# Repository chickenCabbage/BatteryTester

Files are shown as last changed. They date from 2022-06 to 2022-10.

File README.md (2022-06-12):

# BatteryTester
ATmega-based battery tester for FIRST Robotics batteries, designed for ease-of-use for FIRST students and with built-in safety features.

The tester is soldered onto perfboard and is run by a "bare" ATmega328P. It tests battery voltage and state-of-charge using the internal ADC.
Battery internal resistance is tested using high-current loads switched with MOSFETs - by measuring the voltage at the battery terminals under different currents, the tester can calculate the resistance per Ohm's Law.

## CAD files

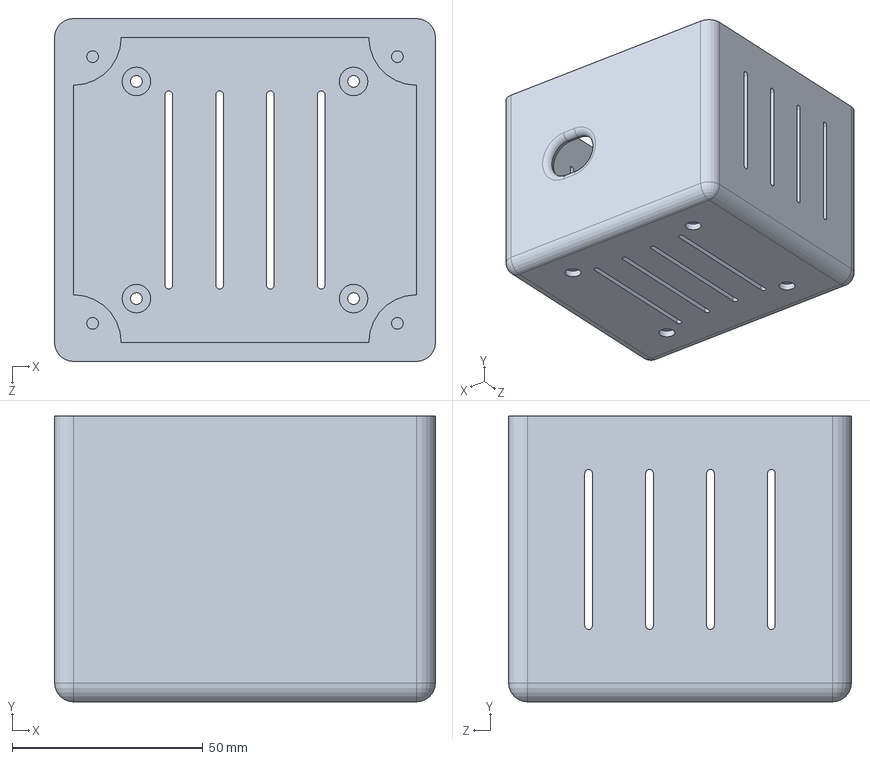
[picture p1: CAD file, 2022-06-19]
3D/Box.SLDPRT
100.0 x 75.0 x 90.0 mm

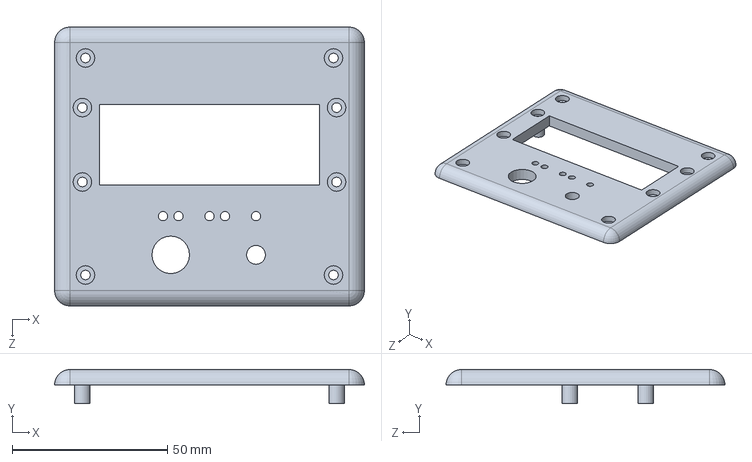
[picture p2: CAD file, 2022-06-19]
3D/Lid.SLDPRT
100.0 x 11.0 x 90.0 mm

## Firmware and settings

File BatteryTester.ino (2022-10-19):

//Pins translation from ATmega328P hardware to Arduino pins according to:
//https://upload.wikimedia.org/wikipedia/commons/c/c9/Pinout_of_ARDUINO_Board_and_ATMega328PU.svg

#define debug false			//print to serial
#define pbPin 1				//PD1, ATmega pin 3

#define quickRunPin 2		//PD2, ATmega pin 4
bool quickRun = false;		//skip the start PB and shorten display times?
#define QUICKFACTOR 2		//by how much are quickRun delays faster?

#define delayPotPin A3		//PC3, ATmega pin pin 26
int printDelay = 1000;		//display time

#define socOnlyPin 0	//PD0, ATmega pin 2
bool socOnly = false;	//show only SOC vs SOC+SOH

#include <LiquidCrystal.h>
#define rs 5	//PD5, ATmega pin 11
#define en 11	//PB3, ATmega pin 17
#define d4 10	//PB2, ATmega pin 16
#define d5 9	//PB1, ATmega pin 15
#define d6 12	//PB4, ATmega pin 18
#define d7 13	//PB5, ATmega pin 19
LiquidCrystal lcd(rs, en, d4, d5, d6, d7);
//16 chars, 2 lines:
#define LCDCOL 16
#define LCDROW 2

#define pbLEDPin 3		//PD3, ATmega pin 5
#define indicatorPin 4	//PD4, ATmega pin 4
#define backlightPin 8	//PE0, ATmega pin 14

#define hcPin A1 //PC2, ATmega pin 25
#define lcPin A2 //PC1, ATmega p  in 24
enum state {
	EC, //extreme current
	HC, //high current
	LC, //low current
	OFF //no current
};

#define BLINKINTERVAL 500	//how long is a blink half-cycle
#define PBCHECKDELAY  10	//how often to check for PB

byte nextChar[] = { //filled arrow right symbol
	B00000,
	B01000,
	B01100,
	B01110,
	B01111,
	B01110,    
	B01100,
	B01000
};

byte omegaChar[] = { //omega/ohms symbol
	B00000,
	B01110,
	B10001,
	B10001,
	B10001,
	B01010,
	B11011,
	B00000
};

#define voltsPin		A5	//PC5, ATmega pin 28
#define ampsPin			A4	//PC3, ATmega pin 27
#define MEASURMENTAMNT	512 //amount of measurments to take
#define MEASURMENTDELAY	2	//interval between each measurment

#define MAXVOLTS	15.4	//max voltage measurable [volts]
#define ISSADC		514		//steady state current [ADC]
#define ISSAMPS		0.035	//steady state current [amps]
#define MAXCURRENT	3.55	//max current measurable [amps]
/* calculation looks ~ like this:
 * avgVolts = map(avgVolts, 0, 1024, 0, MAXVOLTS);
 * avgAmps  = map(avgAmps,  ISSADC, 1024, ISSAMPS, MAXCURRENT);
 */
#define SOC100	13.5 //100% state of charge voltage
#define SOC0	10.5 //0% state of charge voltage

#define SOH100	0.011	//11 mR is a 100% healthy battery per WPIlib.
#define SOH0	0.025	//25 mR is a dead battery.

#define tempPin A0 //PC0, ATmega pin 23
#define MAXTEMP		50 //disallow testing resistance at this temp or higher
#define DISPTEMP	40 //from this temp onward, the temp will be displayed at the "Ready." screen
#define HIGHTEMP	50
#define LOWTEMP		23
#define HIGHTEMPADC	360
#define LOWTEMPADC	535
/* the temperature is calculated based on empiric measurments of the voltage divider with
 * the PTC's and a 10k resistor. temps measured with a FLIR camera.
 * temp calculation is a floatMap() call.
 */

//bind the stage message and the loadState together
struct stage {
	String msg;
	state loadState;
};

//to add another stage, first add it to the enum and setLoadState(), only then add to stages[]
//OFF stage must always be first in the array.
stage stages[] = {
	{ "Unloaded", OFF },
	{ "Low current", LC },
	{ "High current", HC }
};
const byte STAGESAMNT = sizeof(stages) / sizeof(stages[0]);
float volts[STAGESAMNT]; //global storage of parameters
float amps[STAGESAMNT];

/*
 * free pins:
 * PB6, PC6
 * 4, 6, 7
 */


void printAll(String msg, bool clr=false, int wait=0, byte line=0) { //clr, wait and line are optional
	//clr - clear the display before showing msg
	//wait - delay after display
	//line - line to print to on
	if(debug) {
		if(line) Serial.println("LINE " + String(line) + " | " + msg);
		else	 Serial.println(msg);
	}
	if(clr)	 lcd.clear();
	if(line) lcd.setCursor(0, line-1); //line 1 = setCursor(0, 0)
	lcd.print(msg);
	delay(wait);
}

void setup() {
	pinMode(rs, OUTPUT);
	pinMode(en, OUTPUT);
	pinMode(d4, OUTPUT);
	pinMode(d5, OUTPUT);
	pinMode(d6, OUTPUT);
	pinMode(d7, OUTPUT);
	pinMode(hcPin, OUTPUT);
	pinMode(lcPin, OUTPUT);
	pinMode(pbLEDPin, OUTPUT);
	pinMode(pbPin, INPUT_PULLUP);
	pinMode(backlightPin, OUTPUT);
	pinMode(indicatorPin, OUTPUT);
	pinMode(socOnlyPin, INPUT_PULLUP);
	pinMode(quickRunPin, INPUT_PULLUP);
	pinMode(voltsPin, INPUT);
	pinMode(ampsPin,  INPUT);
	pinMode(tempPin, INPUT);
	pinMode(delayPotPin, INPUT);
	
	lcd.begin(LCDCOL, LCDROW);
	lcd.createChar(1, omegaChar);
	lcd.createChar(2, nextChar);
	lcd.home();

	digitalWrite(backlightPin, HIGH);
	setPrintDelay();
	
	if(debug) {
		Serial.begin(9600);
		if(!quickRun) {
			lcd.print("Awaiting serial.");
			while(!Serial);
		}
		Serial.println(String(STAGESAMNT) + "-stage ATP.");
		Serial.println("quickRun is " + String(quickRun) + ", display delay time: " + String(printDelay) + "ms.");
	}
}

void loop() {
	setPrintDelay();
	socOnly = !digitalRead(socOnlyPin);
	
	if(socOnly) {
		digitalWrite(indicatorPin, HIGH);
		setLoadState(OFF);
		measureParams(0);
		printAll("V: " + String(volts[0], 2) + "V", true, 0, 1);
		float soc = floatMap(volts[0], SOC0, SOC100, 0, 100);
		digitalWrite(indicatorPin, LOW);
		printAll("SOC: " + String(soc, 1) + "%", false, printDelay*10, 2);
		
	}
	else {
		setLoadState(OFF);
		
		//before starting a test, check the temperature:
		float temp = floatMap(analogRead(tempPin), 535, 360, 22, 45);
		//over a preset temp, override quickRun and begin showing the temperature:
		if(temp >= DISPTEMP) {
			String tempText = "";
			tempText += String(temp, 1) + "C";
			
			//center the text if displaying "OVER-HEAT!":
			if(temp >= MAXTEMP) {
				for(byte counter=0; counter<((LCDCOL - tempText.length())/2); counter++) {
					tempText = " " + tempText;
				}
			}
			printAll(tempText, true, 0, 2);	
			quickRun = false;
		}
		else lcd.clear();
		//if the temperature is too high, do not allow the user to proceed with the test.
		if(temp >= MAXTEMP) {
			digitalWrite(indicatorPin, HIGH);
			printAll("   OVER-HEAT!", false, BLINKINTERVAL, 1);
			digitalWrite(indicatorPin, LOW);
			delay(BLINKINTERVAL);
			return;
			/* the return allows the re-checking of inputs and of the temp.
			 * instead of using a while loop and delay(), we can use the printAll() delay
			 * and the loop() function.
			 */
		}
		//if the temperature is valid, you will arrive here:
		
		byte	stageCounter = 0;	//iterates over the stages array
		float	avgRes = 0;			//resistance result arrives here
		if(!quickRun) {
			printAll("Ready.", false, 0, 1);
			waitForPB();
		}
		
		//go over every stage:
		digitalWrite(indicatorPin, HIGH);
		for(stageCounter; stageCounter<STAGESAMNT; stageCounter++) {
			doStage(stages[stageCounter], stageCounter);
			if(stageCounter) { //if you're past the first stage (floating voltage test)
				float delta = volts[0] - volts[stageCounter];
				avgRes += (delta / amps[stageCounter]);
			}
		}
		//calculate state of charge based on the OFF voltage measurment
		avgRes = (avgRes / (STAGESAMNT-1)) * 1000; //average the sum and convert to miliR
		avgRes -= 100; //remove the shunt's and the connection's resistance from the result (shunt is 73.33)
		
		lcd.write(1); //show omega symbol for ohms units
		float soc = floatMap(volts[0], SOC0, SOC100, 0, 100);
		digitalWrite(indicatorPin, LOW);
		float soh = floatMap(avgRes, SOH0, SOH100, 0, 100);
		digitalWrite(backlightPin, HIGH);

		bool sohWarn = soh < 0;
		if(!quickRun) {
			//if you've got time: print warnings.
			bool socWarn = soc < 50;
			if(socWarn || sohWarn) {
				printAll("    WARNING!", true, 0, 1);
				String warnings = "";
				if(socWarn) warnings += "SOC";
				if(sohWarn && socWarn) warnings += ", ";
				if(sohWarn) warnings += "SOH";

				//add spaces to center:
				for(byte counter=0; counter<((LCDCOL - warnings.length())/2); counter++) {
					warnings = " " + warnings;
				}
				printAll(warnings, false, printDelay, 2);
				waitForPB();
			}
		}

		//print SOH if it is okay. print resistance if not okay:
		if(!sohWarn) 
			printAll("SOH: " + String((int) soh) + "%", true, 0, 1);
		else {
			printAll("Avg Rint: " + String((int) avgRes), true, 0, 1);
			lcd.setCursor(LCDCOL-2, 0);
			lcd.print("m");
			lcd.write(1);
		}
		printAll("SOC: " + String(soc, 1) + "%", false, printDelay, 2);
		
		waitForPB();
	}
}

int setPrintDelay() {
	quickRun = !digitalRead(quickRunPin);
	if(!quickRun) {
		int pot = analogRead(delayPotPin);
		/* get exponential delay:
		 * y(1024)=10, y(512)=2.5
		 * y is the delay in seconds, and x is the pot reading.
		 * 
		 *     x^2 * 10
		 * y = --------
		 *      1024^2
		 */
		//printDelay = ((10 * pot * pot) / (1024 * 1024)) * 1000;
		//split into multiple lines to prevent overflow and return 0 or negatives:
		float tempCalc = 10*pot;
		tempCalc /= (1024/pot);
		tempCalc /= 1024;
		tempCalc *= 1000;
		printDelay = tempCalc;
	}
	else {
		printDelay = 0;
	}
}

void waitForPB() {
	delay(BLINKINTERVAL);
	bool cursorOn = true; //start out showing the arrow symbol
	bool resetted = false;
	while(true) { //this will be broken by a return call
		lcd.setCursor(LCDCOL-1, LCDROW-1); //show cursor in bottom-right corner
		if(cursorOn) {
			lcd.write(2);
			digitalWrite(pbLEDPin, HIGH);
		}
		else {
			lcd.print(" ");
			digitalWrite(pbLEDPin, LOW);
		}
		//wait for the blinkInterval, while checking for a button press every PushButtonCheckDelay:
		int totalDelay = BLINKINTERVAL;
		for(totalDelay; totalDelay>0; totalDelay-=PBCHECKDELAY) {
			if(digitalRead(pbPin)) resetted = true; //wait for the user to let go of the button
			if(resetted && !digitalRead(pbPin)) return;
			delay(PBCHECKDELAY);
		}
		cursorOn = !cursorOn;
	}
}

void setLoadState(state set) {
	switch(set) {
		case EC: //extreme current, unused
			digitalWrite(hcPin, HIGH);
			digitalWrite(lcPin, HIGH);
			break;
		case HC: //high current
			digitalWrite(hcPin, HIGH);
			digitalWrite(lcPin, LOW);
			break;
		case LC: //low current
			digitalWrite(hcPin, LOW);
			digitalWrite(lcPin, HIGH);
			break;
		default:
			digitalWrite(hcPin, LOW);
			digitalWrite(lcPin, LOW);
	}
}

float floatMap(float val, float fromMin, float fromMax, float toMin, float toMax) {
	//map() does not take floats and returns only integers. hence floatMap().
	return (val-fromMin) * ((toMax-toMin) / (fromMax-fromMin)) + toMin;
}

void doStage(stage currStage, byte index) {
	if(!quickRun) {
		printAll("Testing state:", true, 0, 1);
		printAll(currStage.msg, false, printDelay, 2);
	}

	//take measurments:
	setLoadState(currStage.loadState);
	measureParams(index);
	setLoadState(OFF);

	if(!quickRun) {
		printAll("Voltage: " + String(volts[index], 3) + "V", true, 0, 1);
		printAll("Current: " + String(amps[index], 3) + "A", false, printDelay, 2);
	}
}

void measureParams(byte stage) {
	//remove things that could affect the current:
	lcd.clear();
	digitalWrite(pbLEDPin, LOW);
	digitalWrite(backlightPin, LOW);
	
	//calculate average values over measurmentAmnt measurments with measurmentDelay interval:
	unsigned long voltsSum = 0, ampsSum = 0; //hold sums for avg calc
	int counter, maxCount;
	if(!quickRun)	maxCount = MEASURMENTAMNT;
	else			maxCount = MEASURMENTAMNT/QUICKFACTOR;
	delay(100); //wait to reach steady state
	for(counter=0; counter<maxCount; counter++) {
		voltsSum += analogRead(voltsPin);
		ampsSum += analogRead(ampsPin);
		if(socOnly || quickRun)	delay(MEASURMENTDELAY/QUICKFACTOR);
		else					delay(MEASURMENTDELAY);
	}
	if(printDelay > 200)
		digitalWrite(backlightPin, HIGH);

	float avgVolts, avgAmps;
	if(!quickRun) {
		avgVolts = voltsSum / MEASURMENTAMNT;
		avgAmps  = ampsSum / MEASURMENTAMNT;
	}
	else {
		avgVolts = (voltsSum * QUICKFACTOR) / MEASURMENTAMNT;
		avgAmps  = (ampsSum * QUICKFACTOR) / MEASURMENTAMNT;
	}

	//map results by predefined calibration values:
	avgVolts = floatMap(avgVolts, 0, 1024, 0, MAXVOLTS);
	avgAmps  = floatMap(avgAmps,  ISSADC, 1024, ISSAMPS, MAXCURRENT);
	//assign to global storage:
	volts[stage] = avgVolts;
	amps[stage]  = avgAmps;
}

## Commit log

2022-06-07 Added thermal limiting
    Added a PTC to limit the temperature of the tester and prevent fire/burn hazards.
    [BatteryTester.ino]
2022-06-12 Modified code for SP3T
    Changed the code to work with the SP3T installed on the tester panel.
    The SP3T selects normal (OFF), quickStart (ON 1) and socOnly (ON 2). This means that the jumper locations for these settings have been inverted.
    [BatteryTester.ino]
2022-06-12 Added 3D models
    Made a quick model for a housing with a panel while at the FIRST shop.
    [Box.SLDPRT, Box.STL, Lid.SLDPRT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]
2022-06-19 Fixed models per lessons learnt from print
    [Box.SLDPRT, Lid.SLDPRT]
